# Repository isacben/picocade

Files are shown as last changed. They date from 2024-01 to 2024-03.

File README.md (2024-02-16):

# picocade

An arcade controller for the pico-8 fantasy console powered by a Raspberry Pi Pico and CircuitPython.

> [!WARNING]
> This is Work In Progress! I am still designing the product; the following image is the vision of what I want to build.

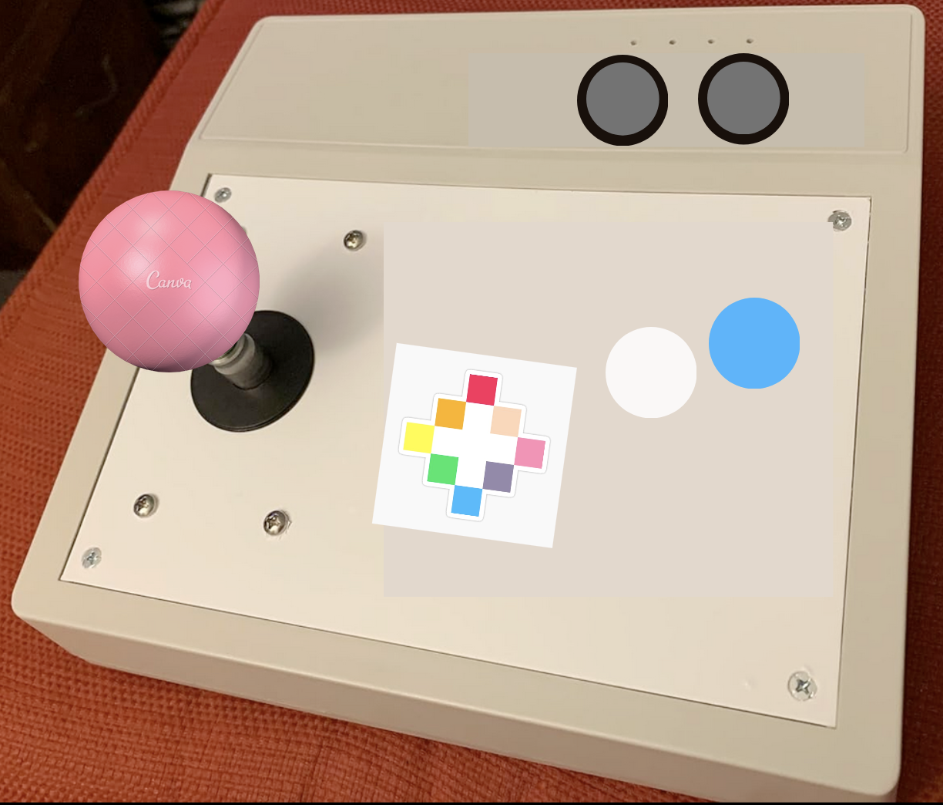
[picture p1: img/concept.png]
PICO-8 arcade controller concept


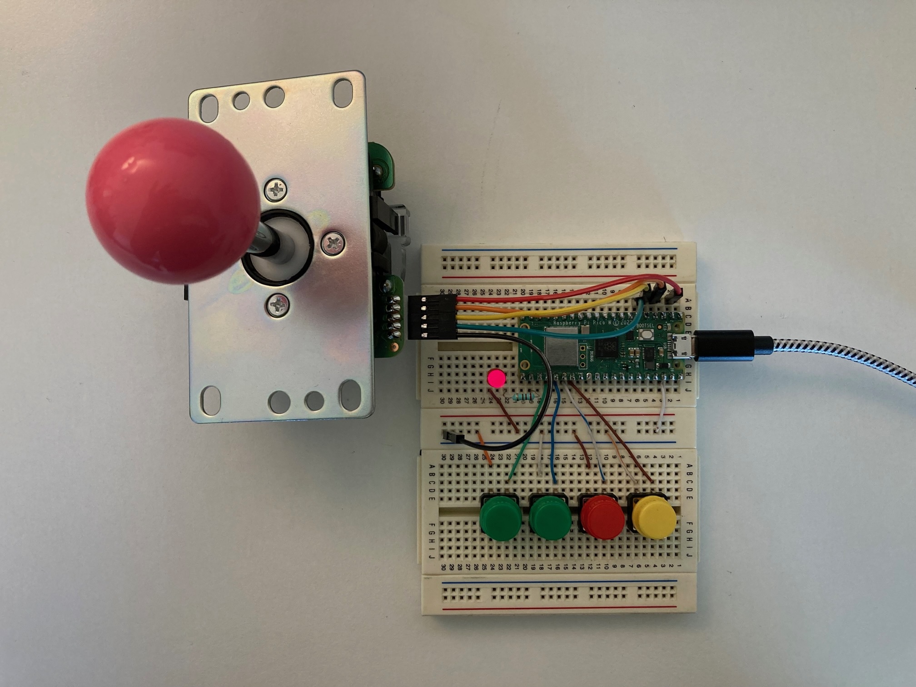
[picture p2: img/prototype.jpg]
Breadboard


## Documentation 

The list of parts (BOM) and the guide to build this arcade controller are here:

[Documentation](https://github.com/isacben/picocade/blob/main/docs/README.md):

1. [Check the Bill Of Materials (list of parts)](https://github.com/isacben/picocade/blob/main/docs/BOM.md)
2. [Work on the hardware](https://github.com/isacben/picocade/blob/main/docs/hardware.md)
3. [Install CircuitPython](https://github.com/isacben/picocade/blob/main/docs/circuitpython.md)
4. [Install the picocade code](https://github.com/isacben/picocade/blob/main/docs/software.md)
5. [Assambly the box](https://github.com/isacben/picocade/blob/main/docs/box.md)

## Author

Isaac Benitez

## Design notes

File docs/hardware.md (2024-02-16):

# Hardware 

## Schematics

If you want to lunch the KiCad project, you might need to import the Raspberry Pi Pico KiCad symbol:

- [Download the Raspberry Pi Pico KiCad symbol](https://forums.raspberrypi.com/viewtopic.php?t=336825)
- [Import KiCad symbols to the global library](https://forum.kicad.info/t/copying-new-symbols-from-one-project-to-another/36338/4)

Otherwise, this schematic shows the connections:

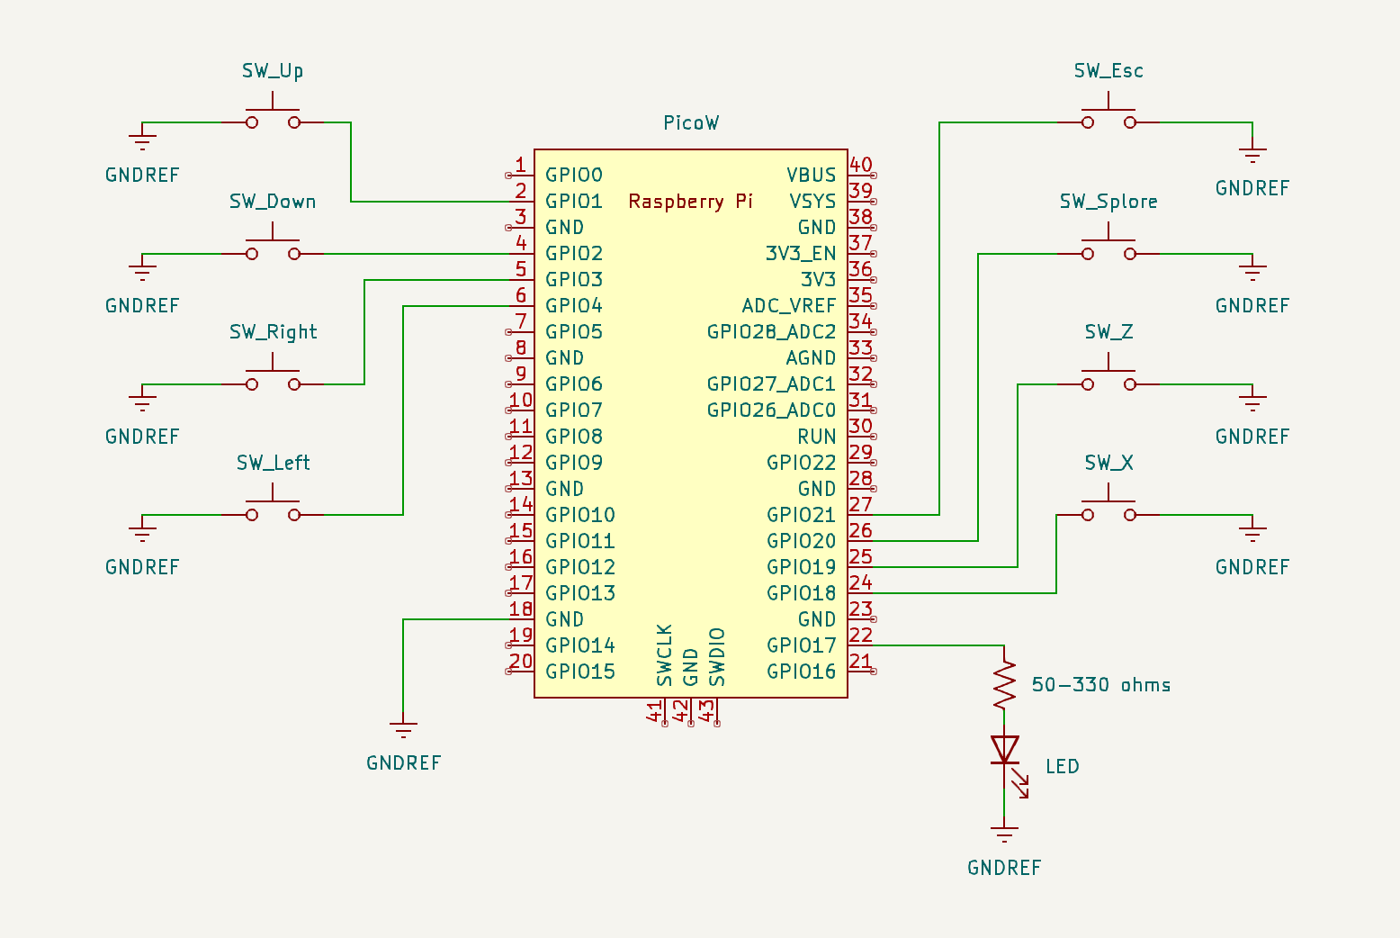
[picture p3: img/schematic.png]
Schematics


## Prototyping

You might want to test your circuit on a breadboard:

Breadboard

> [!TIP]
> At this point, it is a good idea to skip the soldering part and [install CircuitPython](https://github.com/isacben/picocade/blob/main/docs/circuitpython.md) and the [picocade code](https://github.com/isacben/picocade/blob/main/docs/software.md) to test if everything works with PICO-8. Once you pass this test, you can start the soldering.

## Soldering

The final board is just a replica of the circuit in the breadboard:

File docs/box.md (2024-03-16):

# Assambly the box

Make the following holes to the box:

### Aluminum panel

- Two 30mm holes for the arcade buttons
- A 16mm hole for the joystick
- 4 holes to screw the joystick to the panel 

### Top section of the box

- Two 30mm holes for the arcade buttons
- One hole for the led

### Back gray panel

- One 24mm hole for the USB adapter
- Two tiny holes to fix the USB adaptar to the panel

Use the following image as a reference:

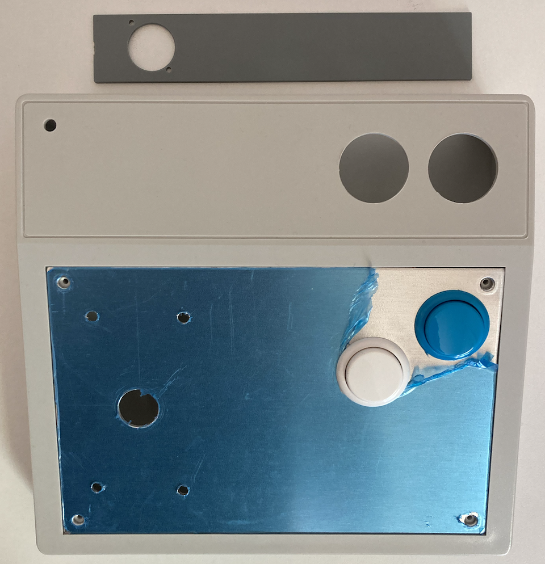
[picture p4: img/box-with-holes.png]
Box with holes


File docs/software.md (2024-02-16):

# Install the software

This step is very simple.

Just copy the code in the [code.py](https://github.com/isacben/picocade/blob/main/firmware/code.py) file and paste it in the `CIRCUITPY/code.py` file in your board.

That's it. Your board should be ready to controll PICO-8. You can test it either with your breadboard prototype or with the soldered circuit connected to the computer.

Enjoy PICO-8 games!

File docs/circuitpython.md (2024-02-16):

# Install CircuitPython

## CircuitPython

The picocade is powered by a Raspberry Pi Pico running CircuitPython. CircuitPython is a version of Python for microcontrollers.

Download CircuitPython for the Raspberry Pi Pico or the Raspberry Pi Pico  W. I am using the second one:

https://circuitpython.org/board/raspberry_pi_pico_w/

[This guide from Adafruit](https://learn.adafruit.com/getting-started-with-raspberry-pi-pico-circuitpython/circuitpython) explains how to install CircuitPython on the Raspberry Pi Pico.

## CircuitPython HID

The picocade also uses the [Adafruit CircuitPython HID library](https://github.com/adafruit/Adafruit_CircuitPython_HID) to make it behave as a keyboard.

Download the CircuitPython libraries bundle from here:

https://circuitpython.org/libraries

Then unzip the downloaded zip file and copy the `adafruit_hid` folder to the `lib` folder on your `CIRCUITPY` drive.

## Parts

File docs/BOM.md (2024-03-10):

# Bill Of Materials (BOM)

| | Item | Count | Cost | Vendor |
| - | ---- | ----- | ---- | --- |
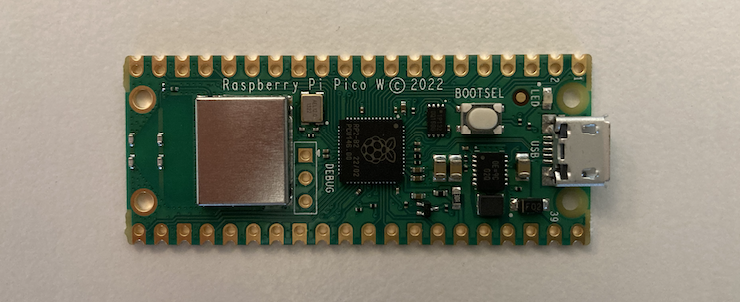
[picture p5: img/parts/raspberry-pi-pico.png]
Raspberry Pi Pico
|  | Raspberry Pi Pico | 1 | $6 | Link |
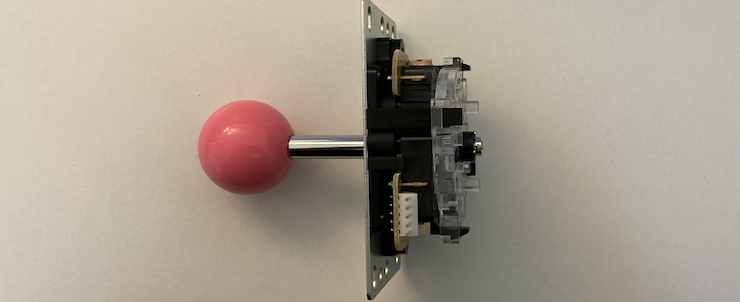
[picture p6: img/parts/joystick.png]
Joystick
|  | Joystick | 1 | $28.00 | Link |
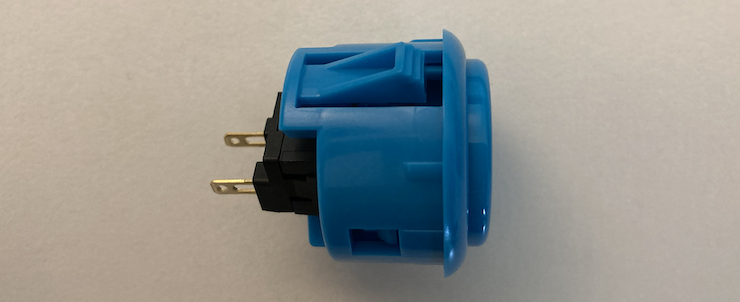
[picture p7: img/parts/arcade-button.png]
Arcade buttons
|  | Arcade buttons | 4 | $22.00 | Link |
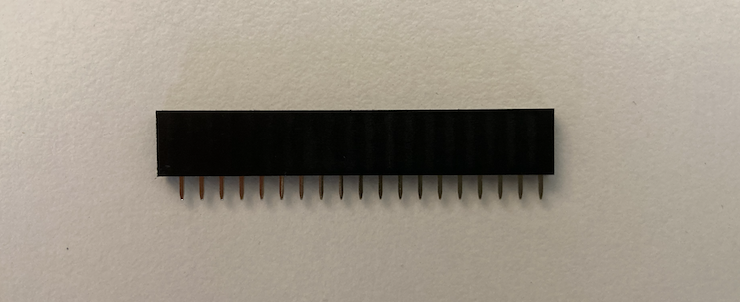
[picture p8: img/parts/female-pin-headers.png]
Female pin header strip
|  | Female pin header strips | 2 | $1.00 | Link |
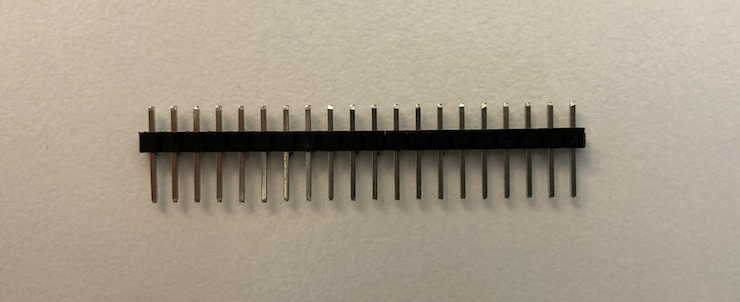
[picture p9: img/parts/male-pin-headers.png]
Male pin header strip
|  | Male pin header strips | 2 | $1.00 | Link |
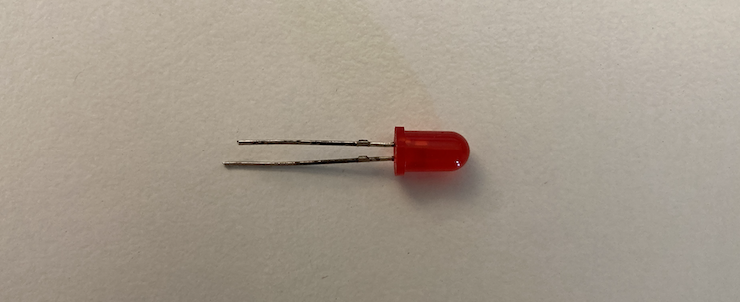
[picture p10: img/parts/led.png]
Led
|  | Led | 1 | $0.20 | Link |
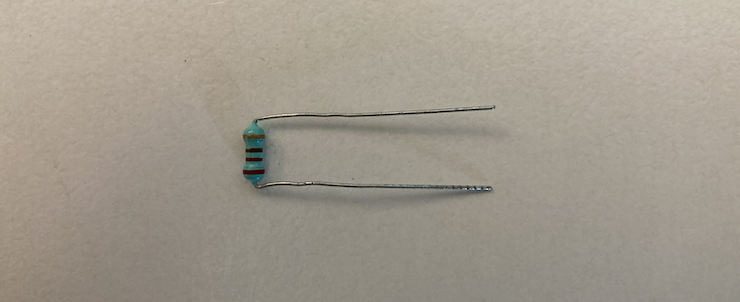
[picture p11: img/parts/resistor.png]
Resistor
|  | Resistor | 1 | $0.20 | Link |
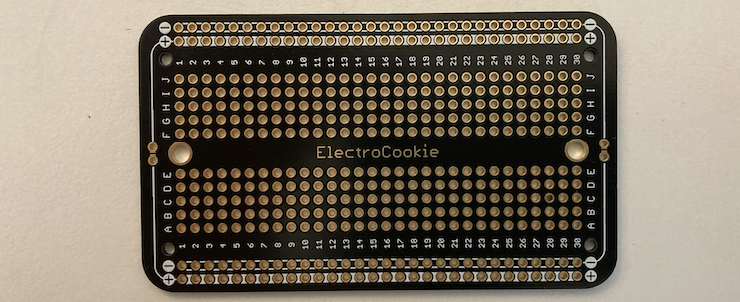
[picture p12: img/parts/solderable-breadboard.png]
Solderable breadboard
|  | Solderable breadboard | 1 | $1.50 | Link |
| Panel mount USB C to USB 3.0 adapter | Panel mount USB C to USB 3.0 adapter (data transfer) | 1 | $8.00 | Link |
| USB to Micro USB data transfer cable | 0.5 feet USB to Micro USB data transfer cable | 1 | $6.99 | Link |
| USB C data transfer cable | USB C data transfer cable | 1 | $12.00 | Link | 
| Enclosure| Enclosure | 1 | $25.00 | Link |

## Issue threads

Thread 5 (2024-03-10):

Links missing in BOM

isacben, 2024-03-10:

Closed 2024-04-14.

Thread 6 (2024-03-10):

Picture of soldered circuit missing in docs

isacben, 2024-03-10:
Document: https://github.com/isacben/picocade/blob/main/docs/hardware.md

isacben, 2024-04-14:
Picture added!

Closed 2024-04-14.

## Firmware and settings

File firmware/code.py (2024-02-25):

import time
import board
import digitalio
import usb_hid
from adafruit_hid.keyboard import Keyboard
from adafruit_hid.keycode import Keycode
from adafruit_hid.keyboard_layout_us import KeyboardLayoutUS

# Set up a keyboard device.
kbd = Keyboard(usb_hid.devices)
layout = KeyboardLayoutUS(kbd)

SPLORE = "splore\n"

pins = (
    board.GP1,
    board.GP2,
    board.GP3,
    board.GP4,
    board.GP18,
    board.GP19,
    board.GP20,
    board.GP21
    )

keys = [
    Keycode.UP_ARROW,
    Keycode.DOWN_ARROW,
    Keycode.RIGHT_ARROW,
    Keycode.LEFT_ARROW,
    Keycode.X,
    Keycode.Z,
    SPLORE,
    Keycode.ESCAPE
]

led = digitalio.DigitalInOut(board.GP17)
led.direction = digitalio.Direction.OUTPUT

buttons = [digitalio.DigitalInOut(pin) for pin in pins]
for button in buttons:
    button.direction = digitalio.Direction.INPUT
    button.pull = digitalio.Pull.UP

while True:
    led.value = True

    for i, button in enumerate(buttons):
        if button.value:
            if keys[i] != SPLORE:
                kbd.release(keys[i])
        else:
            if keys[i] == SPLORE:
                layout.write(SPLORE)
                kbd.release_all()
            else:
                kbd.press(keys[i])
    time.sleep(0.1)

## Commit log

2024-01-20 add resistor count
2024-01-20 add kicad project
    [picocade.kicad_pcb, picocade.kicad_sch]
2024-01-20 add swithces to schematics
    [picocade.kicad_sch]
2024-01-24 first poc of the code for the board
    [picocade.kicad_sch]
2024-01-28 add schematics
    [picocade.kicad_sch]
2024-01-28 add materials to the bom
2024-01-28 undo schematics image resizing
2024-02-04 reorder BOM
2024-02-04 link to BOM
2024-02-04 add USB cables details
2024-02-04 fix BOM table
2024-02-10 add splore and escape buttons
2024-02-11 :baby: fix resistor possition on schematics
    [picocade.kicad_sch]
2024-02-16 document circuitpython guide
2024-02-16 add reference to rb pi pico and cricuitpython
2024-02-25 swap left and right controls
    [picocade.kicad_sch]
2024-02-25 update prototype photo
2024-03-10 add pictures to the BOM
2024-03-10 update rbpi pico picture
2024-03-16 box with holes docs
